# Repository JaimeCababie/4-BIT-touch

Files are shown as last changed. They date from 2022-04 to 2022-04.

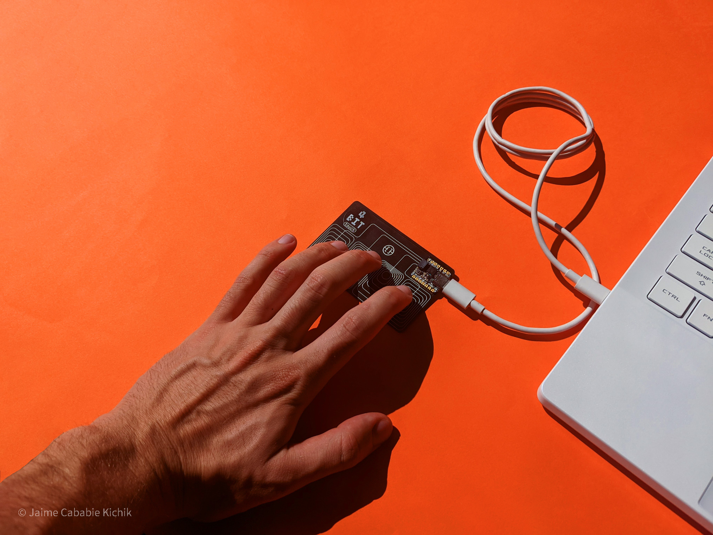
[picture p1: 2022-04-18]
Beauty Shots/Using-the-4BIT.jpg

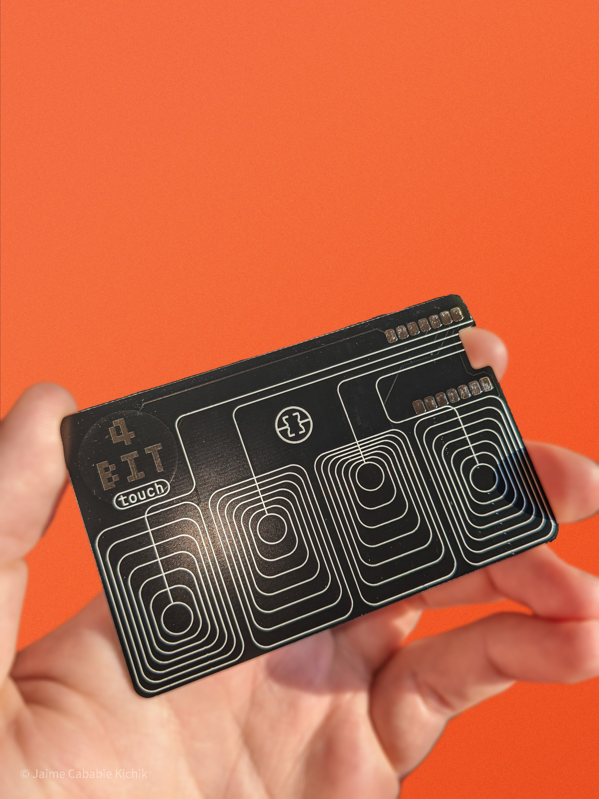
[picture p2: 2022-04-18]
Beauty Shots/HandlingTheFourbit.jpg

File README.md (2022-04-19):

# 4-BIT-touch
4-BIT touch is a macro pad that uses key combos to execute actions. Programed in Circuit Python. Code and PCB files available!

The 4-BIT touch uses a QTPY M0 as the mirocontroler and Circuit Python's HID library. 
There are 5 capacitive touch buttons in the PCB design four of them are ment to be used as inputs and the other one is ment to be used to change profiles. 

There are 15 key combos available when using 4 Keys as inputs: 

Asset 1

How does the code work: 
 
For the QTPY M0 to act as a (Human Device Interface) we need to import the adafruit_hid and usb_hid library to the code:

	import usb_hid
	from adafruit_hid.keyboard import Keyboard
	from adafruit_hid.keycode import Keycode
	from adafruit_hid.keybaord_layout_us import KeyboardLayoutUS

We also need to declare the keyboard class in the code:  

	fourbit = Keyboard(usb_hid.devices)
	layout = KeyboardLayoutUS(fourbit) # this class allows us to input strings as keyboard inputs.

To use the capacitive touch functions of the QTPY M0 we need to import the touchio library:
		
	import touchio
		
Then we need to declare the touch pins in the microcontroller.
#The capacitive touch capacitive touch pins in the QTPY are : A0, A1, A2, A3, TX, RX. 
	
The 4BIT touch has 5 touch pins enabled: A0=key1  A1=key2  A3=key3  A4=key4 and the 4BIT logo.
	
key declaration: 
	
	key1 = touchio.TouchIn(board.A0)
	key2 = touchio.TouchIn(board.A1)
	key3 = touchio.TouchIn(board.A2)
	key4 = touchio.TouchIn(board.A3)
	logo = touchio.TouchIn(board.TX)
	
The sensitivity of the keys can be change using: key.threshold = value. 
	
#In testing, the threshold value that worked the best was 3500. 
	
So a threshold variable was declared: 

	thrv= 3500 

and the threshold value was changed: 

	key1.threshold = thrv
	key2.threshold = thrv
	key3.threshold = thrv
	key4.threshold = thrv
	logo.threshold = thrv
	
The macros that the 4BIT will execute are declared inside functions called actions: 

#There are 15 diferent key combinations available, therefore there are 15 actions called in the code:

first an the function in the code is defined:
#then the macro that the 4BIT is going to execute is declared inside the function definition: 

	def action():
		#select all
 		fourbit.send(Keycode.CONTROL, Keycode.A)

Inside the While Loop the QTPY is sensing which keys are pressed:

	#key value
    	val=0;
    	if key1.value:
        	val=val+0001
    	if key2.value:
        	val=val+0010
    	if key3.value:
        	val=val+0100
    	if key4.value:
        	val=val+1000

When a key is pressed it adds to the value of the variaible val. 
	
To check which combination of keys are being pressed, we need to check the value of val using an if statement. 

For example:
#In this case key1, key2, key3 and key4 are being pressed.

	if (val==1111):

#In this case key1 and key4 are being pressed.

	if (val==1001):
		
When a value is equal to the If statement the action inside of the if statement is executed: 

        if (val==1111): #Action
        	action()
	#the macro inside action() is executed: fourbit.send(Keycode.CONTROL, Keycode.A)

Check out the code examples and try to make your own macros usiing the 4BIT and Circuit Python!

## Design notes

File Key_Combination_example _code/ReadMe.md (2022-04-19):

Copy the Code and lib file to the circuit python drive. 

to change a key combination, you can eddit the files using any text editor.

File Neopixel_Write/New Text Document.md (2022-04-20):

The neopixel_write library is a module included in CircuitPython release file for QTPY. It is a Low level method to control a single Neopixel. 

The QTPY has a Neopixel embeded in its PCB, controlled by the board.NEOPIXEL pin and the power comes from board.NEOPIXEL_POWER pin. 

It is necesary to use the neopixel_write library in the 4-BIT as including a the keyboard_layout_us library and the neopixel library created a memory error.

To use use neopixel_write module we also need to include the digitalio and board library: 

        import board 
        import neopixel_write
        import digitalio
        
Then we need to declare the pin that controls the onboard neopixel:

        neo= digitalio.DigitalInOut(board.NEOPIXEL)
        neo.direction = digitalio.Direction.OUTPUT

We also need to declare the pin that supplies power to the neopixel:

        neo_power=digitalio.DigitalInOut(board.NEOPIXEL_POWER)
        neo_power.direction = digitalio.Direction.OUTPUT

And set the NEOPIXEL_POWER pin on high to supply power to the neopixel: 

    neo_power.value= True

A set_set color function is declared to make it easer to define the color of the leds as neopixel_write module only accepts bytearrays for color values.

        def set_colors(r, g, b):
            global neo
            r = int(r * 255)
            g = int(g * 255)
            b = int(b * 255)
            pixels = bytearray([g, r, b, g, r, b])
            neopixel_write.neopixel_write(neo, pixels)

To use the function, input the RED GREEN and BLUE values in a range from 0 to 1. 

        set_colors(.6,1,0) = RED=153, GREEN=255, BLUE=0
 
 For mmore information visit the Circuit Python documentation.

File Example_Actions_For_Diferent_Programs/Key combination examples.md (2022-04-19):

#This are some examples of Key combination macros that the 4bit is able to execute: 

For Windows:

    #Copy
    fourbit.send(Keycode.CONTROL, Keycode.C)
    #Paste
    fourbit.send(Keycode.CONTROL, Keycode.V)
    #Cut
    fourbit.send(Keycode.CONTROL, Keycode.X)
    #Save
    fourbit.send(Keycode.CONTROL, Keycode.S)
    #undo
    fourbit.send(Keycode.CONTROL, Keycode.Z)
    #redo
    fourbit.send(Keycode.CONTROL,Keycode.Y)
    #Zoom In
    fourbit.send(Keycode.CONTROL, Keycode.EQUALS)
    #Zoom Out
    fourbit.send(Keycode.CONTROL, Keycode.MINUS)
    #screen capture
    fourbit.send(Keycode.WINDOWS, Keycode.LEFT_SHIFT,Keycode.S)
    #screen print
    fourbit.send(Keycode.PRINT_SCREEN)
    #Italics
    fourbit.send(Keycode.CONTROL, Keycode.I)
    #Bold
    fourbit.send(Keycode.CONTROL, Keycode.B)
    #Find
    fourbit.send(Keycode.CONTROL, Keycode.F)
    #Print
    fourbit.send(Keycode.CONTROL, Keycode.P)
    #select all
    fourbit.send(Keycode.CONTROL, Keycode.A)

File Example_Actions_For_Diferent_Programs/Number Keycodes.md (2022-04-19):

The Key Codes for numbers are not included included in the keycode library for circuit python.
For this reason, it is necesary to input the keycode directly in the code like this: fourbit.send(0X1E) #this will type the number one
KeyCodes for numbers: 

  1=0X1E
  2=0X1F
  3=0X20
  4=0X21
  5=0X22
  6=0X23
  7=0X24
  8=0X25
  9=0X26
  0=0X27

You can also declare them as variables to be used later in the code: 

#Copy and paste this variables before the action definitions: 

    ONE = 0X1E
    TWO = 0X1F
    THREE = 0X20
    FOUR = 0X21
    FIVE = 0X22
    SIX = 0X23
    SEVEN = 0X24
    EIGHT = 0X25
    NINE = 0X26
    CERO = 0X27

Example on how to use them:

  fourbit.send(THREE)
  --this will type a 3

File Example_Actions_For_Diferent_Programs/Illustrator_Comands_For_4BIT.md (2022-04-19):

Sintax for Illustrator (and other Adobe Software) commands using the 4BIT and circuitpython:

#The commands in illustrator mainly use key combinattions, because of this, it is optimal to use the fourbit.send() command. 

First we need to import the adafruit_hid libraries:

#Libraies for human device interface

	import usb_hid
	from adafruit_hid.keyboard import Keyboard
	from adafruit_hid.keycode import Keycode
	from adafruit_hid.keyboard_layout_us import KeyboardLayoutUS

	#declare the 4BIT as an input
	fourbit = Keyboard(usb_hid.devices)
	layout = KeyboardLayoutUS(fourbit) 

 Then we will use the same format as the key combination example file: 

	fourbit.send(Keycode.1KEY, Keycode.2KEY, Keycode.3KEY) #replace the "nKEY" with the letter you want to trigger.

Some command examples for Illustrator:

	#Align Text Left
	fourbit.send(Keycode.CONTROL, Keycode.RIGHT_SHIFT, Keycode.L) 

	#Align Text Right
	fourbit.send(Keycode.CONTROL, Keycode.RIGHT_SHIFT, Keycode.R) 

	#Align Text Center
	fourbit.send(Keycode.CONTROL, Keycode.RIGHT_SHIFT, Keycode.C) 

To create your own reference the Default Default Keyboard Shorcut list: 

https://helpx.adobe.com/gr_en/illustrator/using/default-keyboard-shortcuts.html

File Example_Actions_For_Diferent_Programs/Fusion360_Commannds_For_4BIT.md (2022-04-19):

Sintax for fusion360 commands using 4BIT and circuitpython:

# To use the .write function it is necesary  to import the adafruit_hid library and to declare the layout in the code:

#Libraies for human device interface
	import usb_hid
	from adafruit_hid.keyboard import Keyboard
	from adafruit_hid.keycode import Keycode
	from adafruit_hid.keyboard_layout_us import KeyboardLayoutUS

	#declare the 4BIT as an input
	fourbit = Keyboard(usb_hid.devices)
	layout = KeyboardLayoutUS(fourbit) 

In Fusion360 you can use the letter S to search and execute tools. 

	#To execute a tool we can first press S by using:
	fourbit.send(Keycode.S)#This will toggle the search menu
	layout.write("command\n")#Then write te command you want to execute
	fourbit.send(Keycode.ENTER)#And press enter to inicilize it

Some command examples for Fusion360:
	
	fourbit.send(Keycode.S)
	layout.write("extrude\n")
	fourbit.send(Keycode.ENTER)

	fourbit.send(Keycode.S)
	layout.write("Fillet\n")
	fourbit.send(Keycode.ENTER)

	fourbit.send(Keycode.S)
	layout.write("Loft\n")
	fourbit.send(Keycode.ENTER)

	fourbit.send(Keycode.S)
	layout.write("Equal\n")
	fourbit.send(Keycode.ENTER)

	fourbit.send(Keycode.S)
	layout.write("2 point Circle\n")
	fourbit.send(Keycode.ENTER)

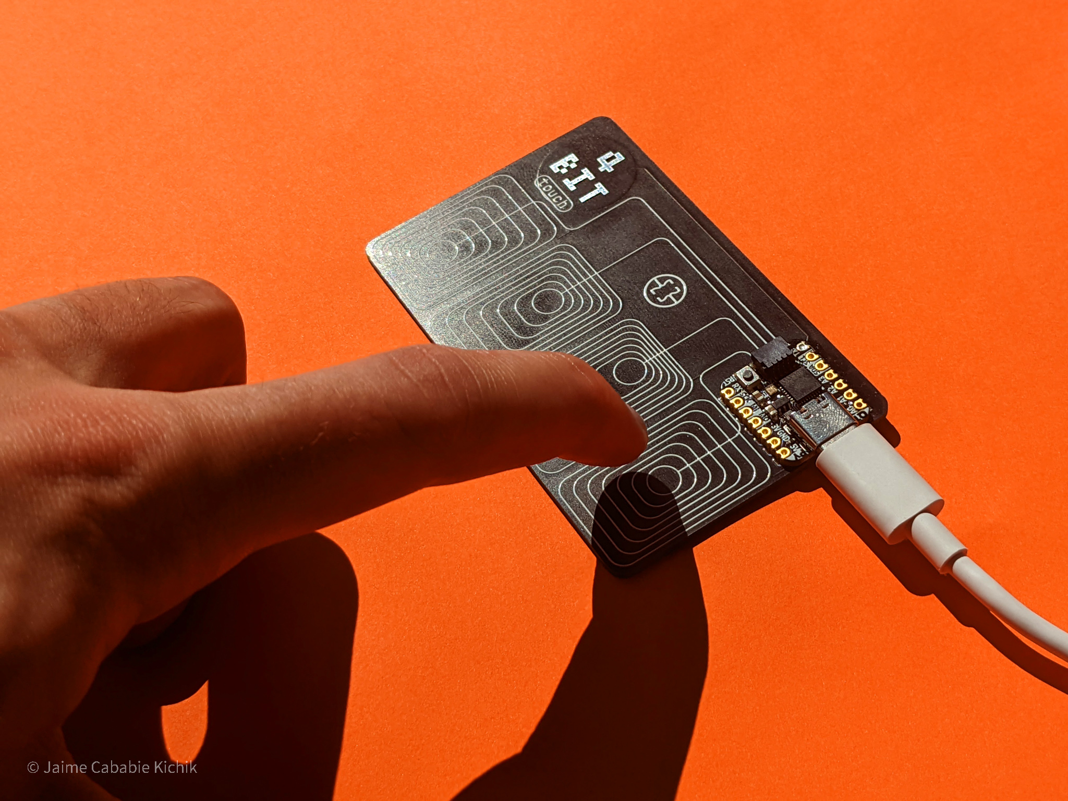
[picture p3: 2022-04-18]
Beauty Shots/Touching-the-4bit.jpg

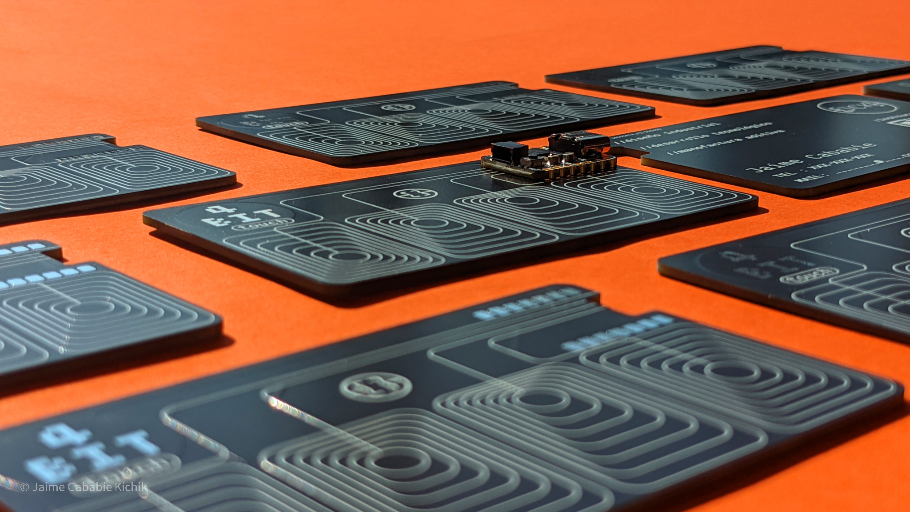
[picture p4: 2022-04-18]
Beauty Shots/Close-Up-Multiple-Fourbit.jpg

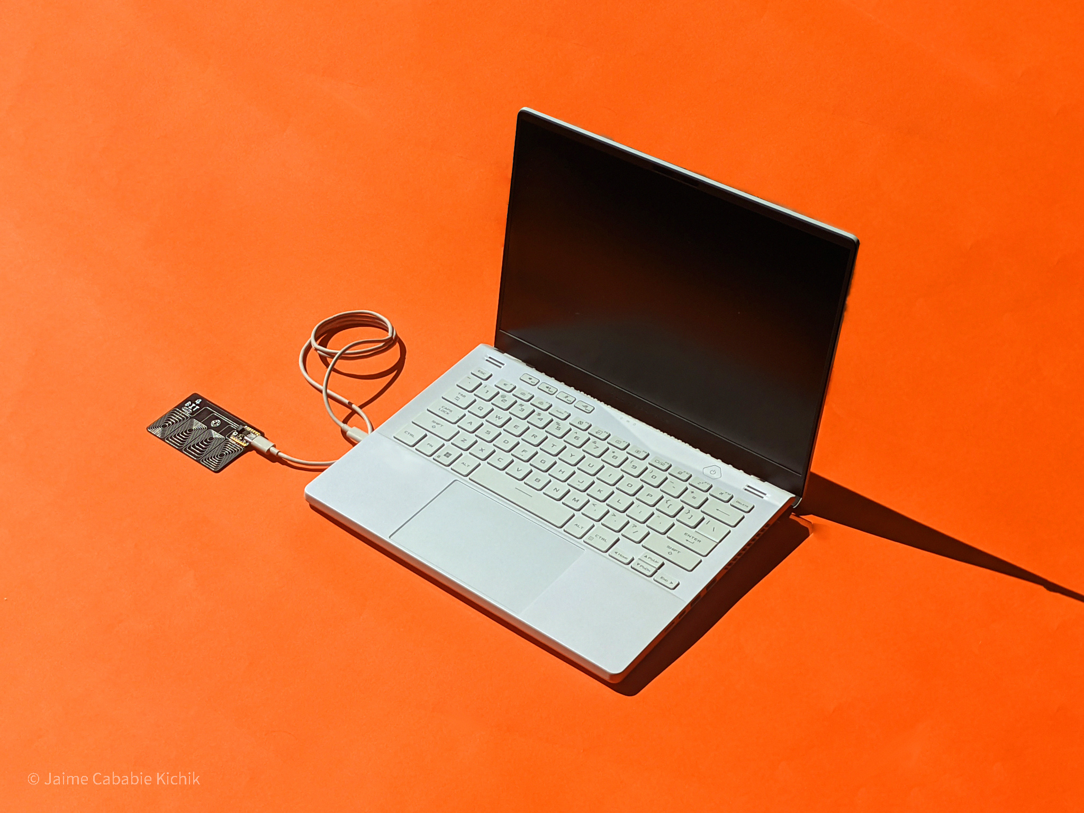
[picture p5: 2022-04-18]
Beauty Shots/Lateralimagen.jpg

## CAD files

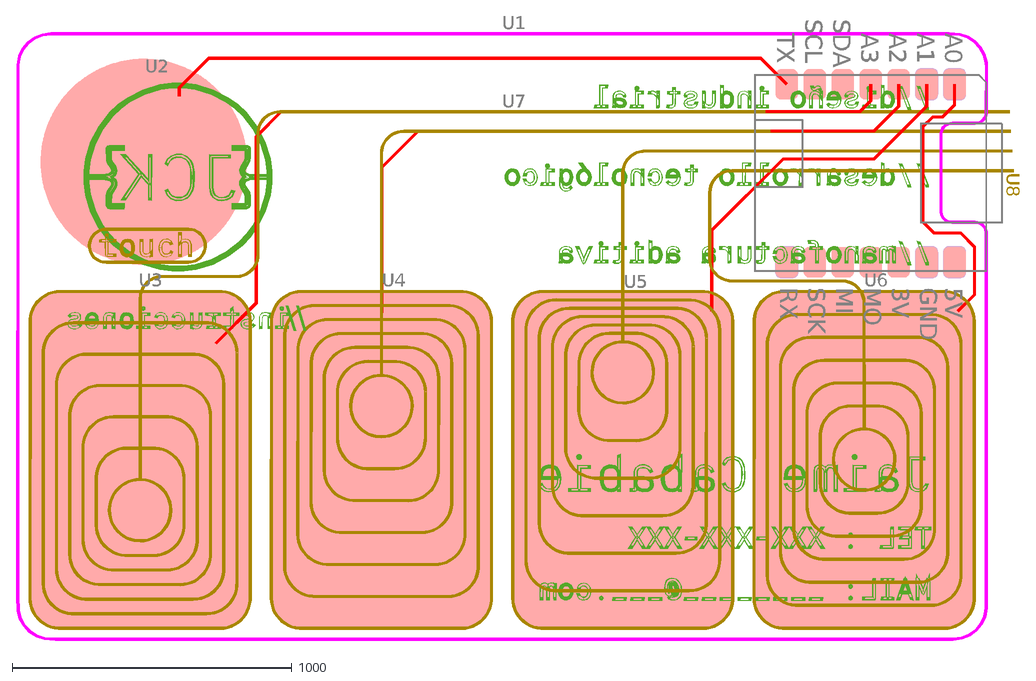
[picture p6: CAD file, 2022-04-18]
PCB_FILES/4-BIT_Touch_PCB.dxf
//
U1
U3
U4
U5
U6
U7
U8
5V
GND
3V
MO
MI
SCK
RX
A0
A1
A2
A3
SDA
SCL
TX
U2

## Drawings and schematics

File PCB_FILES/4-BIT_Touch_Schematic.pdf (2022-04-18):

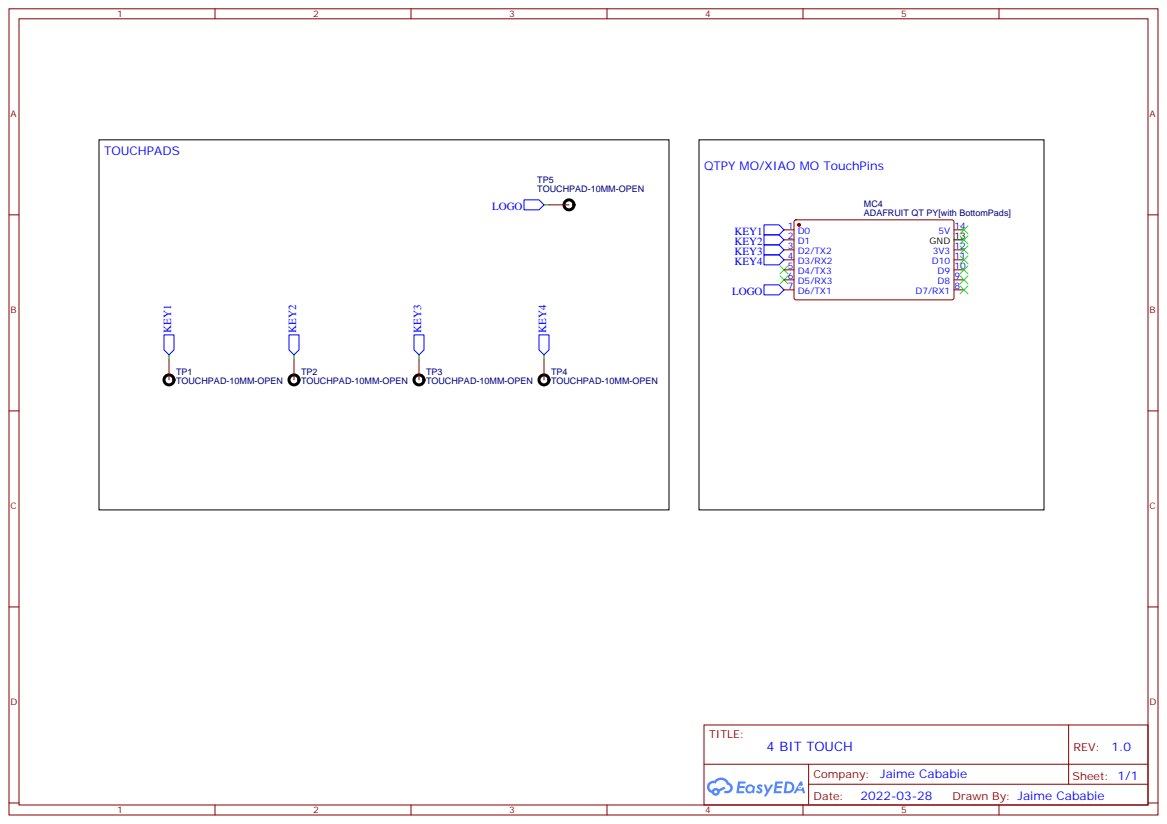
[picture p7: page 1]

QTPY MO/XIAO MO TouchPins

ADAFRUIT QT PY[with BottomPads]

Drawn By: Jaime Cababie

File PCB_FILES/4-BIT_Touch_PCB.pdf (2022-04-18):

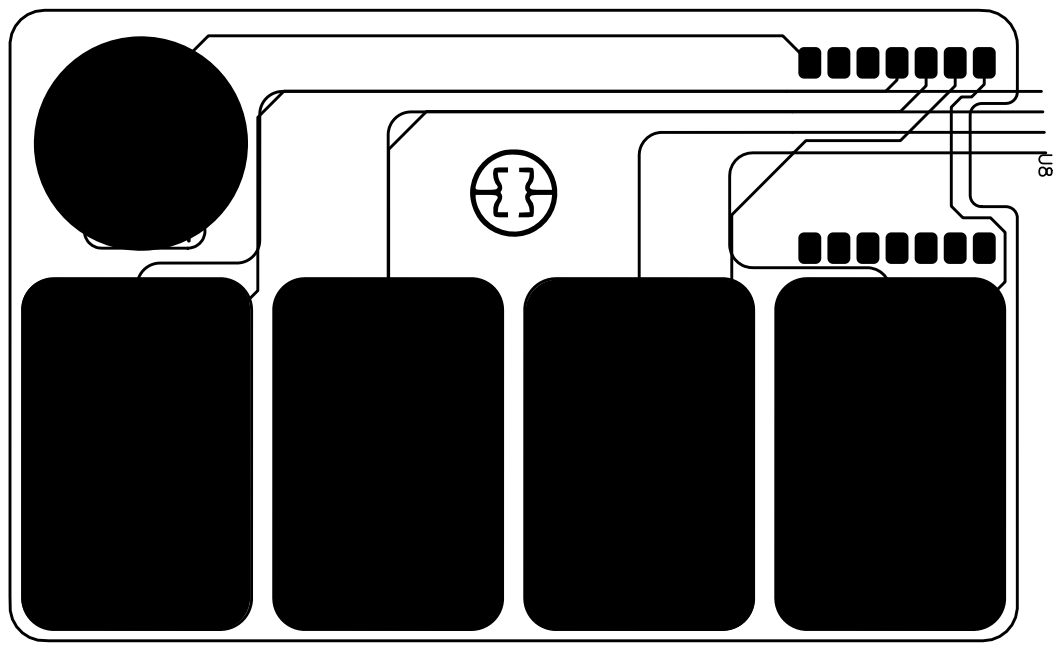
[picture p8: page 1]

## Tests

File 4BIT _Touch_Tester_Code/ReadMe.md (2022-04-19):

Copy the code to the code.py in the QTPY and copy the lib folder to test if the touchpapds are working correctly.

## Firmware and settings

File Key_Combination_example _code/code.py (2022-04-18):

#4bit Key Combinations for Windows Example Code
#Date 2022/15/05
#Version 1.00
#Jaime Cababie

#board Esentials:
import time
import board
import gc

#capacitive touch library
import touchio

#Libraies for human device interface
import usb_hid
from adafruit_hid.keyboard import Keyboard
from adafruit_hid.keycode import Keycode
from adafruit_hid.keybaord_layout_us import KeyboardLayoutUS

#declare the 4BIT as an input
fourbit = Keyboard(usb_hid.devices)
layout = KeyboardLayoutUS(fourbit)

#Neopixel declaration
import neopixel
led = neopixel.NeoPixel(board.NEOPIXEL, 1)
led.brightness=.5

def profilecolor(pr):
    #LED profile values
    if pr==1:
        led[0]=(255,000,000)
    if pr==2:
        led[0]=(000,255,000)
    if pr==3:
        led[0]=(000,000,255)
    if pr==4:
        led[0]=(255,000,255)

#key buffer and touchthreshold values
keybuff= .09# this determines the wait time to stop double inputs
thrv = 3500# this determines the sensitivity of the keys

#key declaration
key1 = touchio.TouchIn(board.A0)
key2 = touchio.TouchIn(board.A1)
key3 = touchio.TouchIn(board.A2)
key4 = touchio.TouchIn(board.A3)
logo = touchio.TouchIn(board.TX)

#Key threshold value
key1.threshold = thrv
key2.threshold = thrv
key3.threshold = thrv
key4.threshold = thrv
logo.threshold = thrv



#Number keycode declaration:
ONE = 0X1E
TWO = 0X1F
THREE = 0X20
FOUR = 0X21
FIVE = 0X22
SIX = 0X23
SEVEN = 0X24
EIGHT = 0X25
NINE = 0X26
CERO = 0X27

#macro functions for each key combos
def action1():#0001
    #Copy
    fourbit.send(Keycode.CONTROL, Keycode.C)
def action2():#0010
    #Paste
    fourbit.send(Keycode.CONTROL, Keycode.V)
def action3():#0100
    #Cut
    fourbit.send(Keycode.CONTROL, Keycode.X)
def action4():#1000
    #Save
    fourbit.send(Keycode.CONTROL, Keycode.S)
def action5():#0011
    #undo
    fourbit.send(Keycode.CONTROL, Keycode.Z)
def action6():#1100
    #redo
    fourbit.send(Keycode.CONTROL,Keycode.Y)
def action7():#0101
    #Zoom In
    fourbit.send(Keycode.CONTROL, Keycode.EQUALS)
def action8():#1010
    #Zoom Out
    fourbit.send(Keycode.CONTROL, Keycode.MINUS)
def action9():#0110
    #screen capture
    fourbit.send(Keycode.WINDOWS, Keycode.LEFT_SHIFT,Keycode.S)
def action10():#1001
    #screen print
    fourbit.send(Keycode.PRINT_SCREEN)
def action11():#0111
    #Italics
    fourbit.send(Keycode.CONTROL, Keycode.I)
def action12():#1110
    #Bold
    fourbit.send(Keycode.CONTROL, Keycode.B)
def action13():#1101
    #Find
    fourbit.send(Keycode.CONTROL, Keycode.F)
def action14():#1011
    #Print
    fourbit.send(Keycode.CONTROL, Keycode.P)
def action15():#1111
    #select all
    fourbit.send(Keycode.CONTROL, Keycode.A)
profile=1
profilecolor(1)

while True:
    #key value
    val=0;
    if key1.value:
        val=val+0001
    if key2.value:
        val=val+0010
    if key3.value:
        val=val+0100
    if key4.value:
        val=val+1000
    if logo.value:
        print("change")
        profile=profile+1
        time.sleep(keybuff)
        if profile>4:
            profile=1
    profilecolor(profile)
    if val>0:
        time.sleep(keybuff)
#comobo value
    #single keypress variations
        if (val==0001): #Action 1
            action1()
        elif (val==0010): #Action 2
            action2()
        elif (val==0100): #Action 3
            action3()
        elif (val==1000): #Action 4
            action4()
    #double keypress variations
        elif (val==0011): #Action 5
            action5()
        elif (val==1100): #Action 6
            action6()
        elif (val==0101): #Action 7
            action7()
        elif (val==1010): #Action 8
            action8()
        elif (val==0110): #Action 9
            action9()
        elif (val==1001): #Action 10
            action10()
    #triple keypress variations
        elif (val==0111): #Action 11
            action11()
        elif (val==1110): #Action 12
            action12()
        elif (val==1101): #Action 13
            action13()
        elif (val==1011): #Action 14
            action14();
    #cuatriple keypress variations
        elif (val==1111): #Action 15
            action15()
        print(val)
        gc.collect()
    time.sleep(0.1)

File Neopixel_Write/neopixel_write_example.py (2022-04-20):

import board
import neopixel_write
import time
import digitalio

neo= digitalio.DigitalInOut(board.NEOPIXEL)
neo.direction = digitalio.Direction.OUTPUT
neo_power=digitalio.DigitalInOut(board.NEOPIXEL_POWER)
neo_power.direction = digitalio.Direction.OUTPUT


def set_colors(r, g, b):
    """Set both neopixels to the specified color.
    r, g, b range from 0 to 1"""
    global neo
    r = int(r * 255)
    g = int(g * 255)
    b = int(b * 255)
    pixels = bytearray([g, r, b, g, r, b])
    neopixel_write.neopixel_write(neo, pixels)

while True:
    neo_power.value= True
    set_colors(.9,.0,.0)
